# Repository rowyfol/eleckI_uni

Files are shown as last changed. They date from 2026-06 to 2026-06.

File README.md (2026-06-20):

# Discrete 2-to-1 Multiplexer (RTL Implementation)

A fully discrete 2-to-1 multiplexer built from NPN transistors, resistors, and diodes — no ICs. This project demonstrates the physical threshold where analog voltage becomes a digital decision.

---

## view schematic online:
[Open on Kicanvas](https://kicanvas.org/?repo=https%3A%2F%2Fgithub.com%2Frowyfol%2FElec101%2Ftree%2Fmain%2FKiCad)

---

## Overview

| | |
|---|---|
| **Course** | Electronics I |
| **Components** | 8× 2N3904 (NPN), Resistors (1K, 10K, 330Ω), Diodes (1N4148), LED, Potentiometer |
| **Logic Family** | RTL (Resistor-Transistor Logic) |
| **Input** | D₀, D₁ (data), S (select) |
| **Output** | Y (drives LED via Q8 buffer) |

The MUX implements the standard Boolean equation using a NAND-NAND structure:

$$Y = (D_0 \cdot \overline{S}) + (D_1 \cdot S)$$

Decomposed into three NAND gates for transistor-level implementation:

$$Y = \overline{\overline{(D_0 \cdot \overline{S})} \cdot \overline{(D_1 \cdot S)}}$$

---

## Circuit Architecture

### Block Diagram

```mermaid
graph LR
    S[S Input] --> Q1[NOT Gate<br/>Q1 Inverter]
    Q1 --> Sbar[S̄]

    D0[D0 Input] --> NAND1[NAND1<br/>Q2·Q3]
    Sbar --> NAND1

    D1[D1 Input] --> NAND2[NAND2<br/>Q4·Q5]
    S --> NAND2

    NAND1 --> N1[N1]
    NAND2 --> N2[N2]

    N1 --> NAND3[NAND3<br/>Q6·Q7]
    N2 --> NAND3

    NAND3 --> Y[Y Output]
    Y --> Q8[LED Driver<br/>Q8]
    Q8 --> LED[LED]
```

### Transistor-Level Schematic

```
+5V ────────────────────────────────────────────────
 │       │       │       │       │       │
[1K]   [1K]    [1K]    [1K]    [1K]   [330Ω]
 │       │       │       │       │       │
 ├─Q2─┐  ├─Q4─┐  ├─Q6─┐  │       │      LED
 │    │  │    │  │    │  │       │       │
D0   Q3  D1   Q5  N1   Q7  │       │      Q8
 │    │  │    │  │    │  │       │       │
 └─10K┘  └─10K┘  └─10K┘  │       │       │
    │       │       │      │       │       │
   GND     GND     GND    │       │      GND
                            │       │
                           Q1      [10K]
                            │       │
                            S───────┘
                           GND
```

### Stage Breakdown

| Stage | Transistors | Function | Equation |
|---|---|---|---|
| **Inverter** | Q1 | Produces S̄ from S | $\overline{S}$ |
| **NAND1** | Q2, Q3 | Computes $\overline{D_0 \cdot \overline{S}}$ | $N_1 = \overline{D_0 \cdot \overline{S}}$ |
| **NAND2** | Q4, Q5 | Computes $\overline{D_1 \cdot S}$ | $N_2 = \overline{D_1 \cdot S}$ |
| **NAND3** | Q6, Q7 | Final output | $Y = \overline{N_1 \cdot N_2}$ |
| **Driver** | Q8 | LED buffer | $\text{LED} = Y$ |

---

## Truth Table

| $S$ | $D_0$ | $D_1$ | $N_1$ | $N_2$ | $Y$ | LED |
|:---:|:---:|:---:|:---:|:---:|:---:|:---:|
| 0 | 0 | 0 | 1 | 1 | 0 | OFF |
| 0 | 1 | 0 | 0 | 1 | 1 | ON |
| 0 | 1 | 1 | 0 | 1 | 1 | ON |
| 1 | 0 | 0 | 1 | 1 | 0 | OFF |
| 1 | 0 | 1 | 1 | 0 | 1 | ON |
| 1 | 1 | 0 | 1 | 0 | 0 | OFF |
| 1 | 1 | 1 | 1 | 0 | 1 | ON |

**Key observation:** When $S=0$, output follows $D_0$. When $S=1$, output follows $D_1$.

---

## The Threshold Crossing Demo

Instead of a digital switch for the Select input, a **10K potentiometer** is wired as a voltage divider:

$$V_{wiper} = V_{CC} \times \frac{R_2}{R_1 + R_2}$$

As the knob rotates from 0 to 5V, the input transistor Q1 crosses its base-emitter threshold:

| $V_{wiper}$ | Q1 State | $\overline{S}$ | MUX Selects |
|:---:|:---:|:---:|:---:|
| 0V → 0.6V | OFF (Cutoff) | HIGH (~5V) | **D₀** |
| **~0.7V** | **Threshold** | **Transition** | **Snap** |
| 0.8V → 5V | ON (Saturation) | LOW (~0.2V) | **D₁** |

The LED does not fade — it **snaps** from one state to the other at approximately **0.7V**, demonstrating the physical origin of digital logic.

---

## Measured Voltages (Verification)

| Node | Expected | Measured | Status |
|---|---|---|---|
| Q1 Collector (S̄) | ~0V when S=HIGH | 26 mV | ✅ |
| Q2 Collector (NAND1) | ~5V when D₀=HIGH, S̄=LOW | 4.61 V | ✅ |
| Q4 Collector (NAND2) | ~5V when D₁=LOW | 4.61 V | ✅ |
| Q6 Collector (NAND3) | ~0V when both inputs HIGH | 57 mV | ✅ |

---

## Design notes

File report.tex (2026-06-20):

\documentclass[11pt,a4paper]{article}

% ============================================================
%  ELECTRONICS I PROJECT REPORT
% ============================================================

\usepackage[utf8]{inputenc}
\usepackage[T1]{fontenc}
\usepackage{geometry}
\usepackage{xcolor}
\usepackage{graphicx}
\usepackage{amsmath,amssymb}
\usepackage{booktabs}
\usepackage{caption}
\usepackage{enumitem}
\usepackage{fancyhdr}
\usepackage{titlesec}
\usepackage{tcolorbox}
\usepackage{tikz}
\usepackage{pgfplots}
\usepackage{float}
\usepackage{subcaption}
\usepackage{multicol}
\usepackage{wrapfig}
\pgfplotsset{compat=1.18}
\usetikzlibrary{arrows.meta,positioning,calc,shapes.gates.logic.IEC,decorations.pathmorphing,fit,backgrounds}

\geometry{left=2.8cm, right=2.8cm, top=2.8cm, bottom=3.2cm}

% ---------- PROFESSIONAL FONTS ----------
\usepackage{libertinus}
\usepackage{newtxmath}
\usepackage[scaled=0.95]{helvet}

% ---------- COLOR SCHEME ----------
\definecolor{primary}{RGB}{35, 55, 85}
\definecolor{accent}{RGB}{180, 95, 55}
\definecolor{secondary}{RGB}{75, 115, 145}
\definecolor{lightgray}{RGB}{240, 240, 238}
\definecolor{medgray}{RGB}{140, 140, 135}
\definecolor{darktext}{RGB}{25, 30, 35}

\pagecolor{white}
\color{darktext}

% ---------- HYPERREF ----------
\usepackage{hyperref}
\hypersetup{colorlinks=true, linkcolor=secondary, urlcolor=secondary, citecolor=medgray}

% ---------- SECTION STYLING ----------
\titleformat{\section}
  {\Large\bfseries\sffamily\color{primary}}
  {\thesection}{1em}{}
  [\vspace{-0.8em}\textcolor{accent}{\rule{\textwidth}{1.2pt}}]
\titleformat{\subsection}
  {\large\bfseries\sffamily\color{primary!85}}
  {\thesubsection}{1em}{}
\titleformat{\subsubsection}
  {\normalsize\bfseries\sffamily\color{medgray}}
  {\thesubsubsection}{1em}{}
\titlespacing*{\section}{0pt}{2.5em}{1.2em}
\titlespacing*{\subsection}{0pt}{2em}{0.8em}

% ---------- HEADER ----------
\pagestyle{fancy}
\fancyhf{}
\fancyhead[L]{\small\sffamily\textcolor{medgray}{Electronics I \;\textbullet\; Discrete 2-to-1 Multiplexer}}
\fancyhead[R]{\small\sffamily\textcolor{medgray}{\thepage}}
\renewcommand{\headrulewidth}{0.5pt}
\renewcommand{\headrule}{\hbox to\headwidth{\color{secondary}\leaders\hrule height \headrulewidth\hfill}}
\fancyfoot[C]{\footnotesize\textcolor{medgray}{\textit{}}}

% ---------- CAPTIONS ----------
\captionsetup{font=small, labelfont={bf,sf,color=primary}, labelsep=quad, format=plain}

% ---------- TCOLORBOX ----------
\tcbuselibrary{skins,breakable}

\newtcolorbox{note}[1][]{
  enhanced, colback=lightgray, colframe=medgray!40, arc=1mm, boxrule=0.6pt,
  left=10pt, right=10pt, top=8pt, bottom=8pt, fontupper=\small, #1
}

\newtcolorbox{fix}[1][]{
  enhanced, colback=white, colframe=accent!60, arc=1mm, boxrule=1pt,
  left=10pt, right=10pt, top=8pt, bottom=8pt, fontupper=\small,
  title={\small\bfseries\sffamily What Went Wrong}, fonttitle=\color{accent!80!black},
  attach boxed title to top left={yshift=-2mm,xshift=6mm},
  boxed title style={colback=accent!15, arc=1mm}, #1
}

\newtcolorbox{keypoint}[1][]{
  enhanced, colback=secondary!5, colframe=secondary!50, arc=1mm, boxrule=0.8pt,
  left=10pt, right=10pt, top=8pt, bottom=8pt, fontupper=\small,
  title={\small\bfseries\sffamily Key Point}, fonttitle=\color{secondary!80!black},
  attach boxed title to top left={yshift=-2mm,xshift=6mm},
  boxed title style={colback=secondary!15, arc=1mm}, #1
}

% ---------- CUSTOM ----------
\newcommand{\VCC}{+5\,\text{V}}
\newcommand{\GND}{0\,\text{V}}

% ============================================================
\begin{document}

% ============================================================
%  TITLE PAGE
% ============================================================
\begin{titlepage}
\begin{center}

\vspace*{1.5cm}

{\Large\sffamily\textcolor{secondary}{ELECTRONICS I PROJECT}}\\[1cm]

{\Huge\bfseries\textcolor{primary}{Building a 2-to-1 Multiplexer}}\\[0.25cm]
{\Huge\bfseries\textcolor{primary}{From Scratch }}\\[0.25cm]

\vspace{1.2cm}

\textcolor{accent}{\rule{0.7\textwidth}{1.5pt}}

\vspace{1cm}

\vspace{2cm}

\begin{tabular}{rl}
\\
\textbf{Course:} & Electronics I \\
\textbf{Supervisor:} & Dr. Shatrian \\
\textbf{Authors:} & Ashkan Namjoo \quad \& \quad Sadra Jahanshalo \\
\textbf{University:} & Shahid Bahonar University of Kerman \\
\textbf{Date:} & \today \\
\end{tabular}

\vfill

\end{center}
\end{titlepage}

% ============================================================
%  ABSTRACT
% ============================================================
\begin{tcolorbox}[
  enhanced, colback=lightgray, colframe=primary, arc=0mm, boxrule=1pt,
  left=12pt, right=12pt, top=10pt, bottom=10pt,
  title={\large\bfseries\sffamily Abstract},
  fonttitle=\color{white}, coltitle=white,
  attach boxed title to top left={yshift=-4mm, xshift=8mm},
  boxed title style={colback=primary, arc=0mm}
]
This report documents the design and construction of a fully discrete 2-to-1 multiplexer using only NPN transistors and resistors. The circuit implements the Boolean function $Y = (D_0 \cdot \overline{S}) + (D_1 \cdot S)$ using Resistor-Transistor Logic (RTL). After initial debugging to resolve a grounding issue in the output stage, the circuit was successfully verified against its truth table. Finally, a potentiometer was used to sweep the Select input voltage, revealing the sharp threshold ($\approx 0.7\,\text{V}$) where the transistor physically transitions from OFF to ON.
\end{tcolorbox}

\vspace{0.8em}
\tableofcontents
\newpage

% ============================================================
\section{Introduction}
% ============================================================

In our digital logic course, we mostly looked at multiplexers as abstract black boxes. You have inputs, a select line, and an output, and the select line chooses which input passes through. They look clean on paper, but we wanted to see how they actually work using physical wires and transistors.

So, we decided to build one from scratch. The rule was simple: no integrated circuits allowed. Just discrete transistors and resistors. If the logic holds up, it should work regardless of what level you build it at.

This project was split into two parts. First, we built the MUX and made sure it worked. Second, we replaced the Select switch with a potentiometer to watch what happens physically when you slowly sweep the voltage across the transistor's threshold.

% ============================================================
\section{Theory and Logic Design}
% ============================================================

\subsection{The Multiplexer Function}

A 2-to-1 multiplexer routes one of two data inputs to a single output based on a select bit. The Boolean equation is:

\begin{equation}
Y = (D_0 \cdot \overline{S}) + (D_1 \cdot S)
\label{eq:mux}
\end{equation}

When $S = 0$, the output equals $D_0$. When $S = 1$, the output equals $D_1$.

\subsection{From AND-OR to NAND-NAND}

Transistors are naturally good at making NAND gates, but not AND-OR structures directly. Using De Morgan's theorem, Equation~\eqref{eq:mux} becomes:

\begin{equation}
Y = \overline{\,\overline{(D_0 \cdot \overline{S})} \cdot \overline{(D_1 \cdot S)}\,}
\label{eq:nand}
\end{equation}

This requires:
\begin{itemize}[leftmargin=2em]
  \item One inverter to generate $\overline{S}$
  \item Three NAND gates (two for the inner terms, one for the final combination)
\end{itemize}

Figure~\ref{fig:logic} shows the complete logic diagram.

\begin{figure}[H]
\centering
\begin{tikzpicture}[
  logic gate IEC,
  line join=round,
  line cap=round,
  scale=1.15,
  transform shape
]

% --- Gates ---
\node[not gate, draw=primary, line width=1.5pt, minimum width=1cm, minimum height=0.8cm] (not) at (0,0) {};

\node[nand gate, draw=accent, line width=1.5pt, logic gate inputs=nn, minimum width=1.4cm, minimum height=1cm] (nand1) at (4.5,2.2) {};
\node[nand gate, draw=accent, line width=1.5pt, logic gate inputs=nn, minimum width=1.4cm, minimum height=1cm] (nand2) at (4.5,-2.2) {};
\node[nand gate, draw=secondary, line width=1.5pt, logic gate inputs=nn, minimum width=1.4cm, minimum height=1cm] (nand3) at (9,0) {};

% --- Inputs ---
\draw[primary, line width=1.2pt, -{Stealth}] (-2.5,0) -- (not.input) 
  node[pos=0.35, above, font=\small, fill=white, inner sep=2pt] {$S$};

\draw[primary, line width=1.2pt, -{Stealth}] (-2.5,2.2) -- (nand1.input 1) 
  node[pos=0.35, above, font=\small, fill=white, inner sep=2pt] {$D_0$};
\draw[primary, line width=1.2pt, -{Stealth}] (-2.5,-2.2) -- (nand2.input 2) 
  node[pos=0.35, below, font=\small, fill=white, inner sep=2pt] {$D_1$};

% --- S branch to NAND2 (top input) ---
\draw[primary, line width=1pt] (-2.5,0) -- (-1.2,0);
\fill[primary] (-1.2,0) circle (1.5pt);  % junction dot
\draw[primary, line width=1pt] (-1.2,0) -- (-1.2,-1.6) -- (nand2.input 1);

% --- Sbar from NOT to NAND1 (bottom input) ---
\draw[primary, line width=1pt] (not.output) -- (1.5,0) -- (1.5,1.6) -- (nand1.input 2);
\node[font=\small, fill=white, inner sep=2pt, anchor=west] at (1.55,0.8) {$\overline{S}$};

% --- NAND1 / NAND2 outputs to NAND3 ---
\draw[accent, line width=1.2pt] (nand1.output) -- ++(1.2,0) |- (nand3.input 1);
\draw[accent, line width=1.2pt] (nand2.output) -- ++(1.2,0) |- (nand3.input 2);

% --- Final output ---
\draw[secondary, line width=1.5pt, -{Stealth}] (nand3.output) -- ++(1.5,0) 
  node[right, font=\small, fill=white, inner sep=2pt] {$Y$};

% --- Gate labels ---
\node[font=\footnotesize\sffamily\bfseries, color=accent, above=0.25cm of nand1] {NAND1};
\node[font=\footnotesize\sffamily\bfseries, color=accent, below=0.25cm of nand2] {NAND2};
\node[font=\footnotesize\sffamily\bfseries, color=secondary, above=0.25cm of nand3] {NAND3};

\end{tikzpicture}
\caption{Logic diagram: NOT gate produces $\overline{S}$, NAND1 and NAND2 generate the intermediate terms, and NAND3 combines them for the final output.}
\label{fig:logic}
\end{figure}

\subsection{Why NAND Works for Transistors}

A NAND gate is built by placing two NPN transistors in series between the output node and ground. A pull-up resistor connects the output to +5V.

\begin{itemize}[leftmargin=2em]
  \item If either transistor is OFF, the path to ground is broken. The output stays HIGH.
  \item Only when both transistors are ON does current flow to ground, pulling the output LOW.
\end{itemize}

This is perfect for RTL because a single transistor can block the entire path.

% ============================================================
\section{Transistor-Level Implementation}
% ============================================================

\subsection{Stage 1: The Inverter (Q1)}

The inverter uses one NPN transistor with a 1K$\Omega$ collector pull-up and a 10K$\Omega$ base resistor.

\begin{itemize}[leftmargin=2em]
  \item Input LOW (0V): No base current. Transistor is OFF. The 1K$\Omega$ resistor pulls the output up to +5V.
  \item Input HIGH (5V): Base current flows. Transistor saturates. Output drops to roughly 0.2V.
\end{itemize}

\subsection{Stage 2: NAND Gates (Q2-Q7)}

Each NAND gate uses two transistors in series:

\begin{table}[H]
\centering
\caption{NAND gate transistor mapping.}
\begin{tabular}{@{}clll@{}}
\toprule
\textbf{Gate} & \textbf{Transistors} & \textbf{Input A} & \textbf{Input B} \\
\midrule
NAND1 & Q2 (top), Q3 (bottom) & $D_0$ & $\overline{S}$ \\
NAND2 & Q4 (top), Q5 (bottom) & $D_1$ & $S$ \\
NAND3 & Q6 (top), Q7 (bottom) & $N_1$ & $N_2$ \\
\bottomrule
\end{tabular}
\end{table}

The top transistor's collector connects to the pull-up resistor. Its emitter connects to the bottom transistor's collector. The bottom transistor's emitter goes straight to ground.

\subsection{Stage 3: Output Driver (Q8)}

Q8 acts as a simple buffer. When $Y$ is HIGH, base current flows through the 10K$\Omega$ resistor, Q8 turns ON, and the LED lights up. The 330$\Omega$ resistor limits the current to approximately 8mA to keep the LED safe.

\subsection{Complete Circuit Schematic}

Figure~\ref{fig:schematic} shows the full transistor-level implementation. This is the diagram we used to wire the breadboard.

\begin{figure}[H]
\centering

\caption{Complete RTL schematic of the 2-to-1 multiplexer. The circuit uses 8 transistors, 5 pull-up resistors (1K$\Omega$), 8 base resistors (10K$\Omega$), and one LED current-limiting resistor (330$\Omega$).}
\label{fig:schematic}
\end{figure}
% ============================================================
\section{Design Calculations}
% ============================================================

When building a circuit from discrete components, you cannot just guess resistor values. Every value affects how the transistor behaves. Here is how we chose ours.

\subsection{Base Resistor (10K$\Omega$)}

The base resistor controls how much current enters the transistor base. For the transistor to act as a solid switch, it must be in \textit{deep saturation}---not just barely on.

The collector current is set by the pull-up resistor:
\begin{equation}
I_C \approx \frac{V_{CC}}{R_C} = \frac{5\,\text{V}}{1\,\text{k}\Omega} = 5\,\text{mA}
\end{equation}

To guarantee saturation, we use a forced beta ($\beta_{forced}$) much lower than the transistor's actual current gain (typically 100--300 for 2N3904). We chose $\beta_{forced} \approx 12$:

\begin{equation}
I_B = \frac{I_C}{\beta_{forced}} = \frac{5\,\text{mA}}{12} \approx 0.4\,\text{mA}
\end{equation}

Then the base resistor is:
\begin{equation}
R_B = \frac{V_{CC} - V_{BE}}{I_B} = \frac{5\,\text{V} - 0.7\,\text{V}}{0.4\,\text{mA}} \approx 10.7\,\text{k}\Omega
\end{equation}

We used the standard value of 10K$\Omega$.
\subsection{Collector Pull-Up Resistor (1K$\Omega$)}

The pull-up resistor determines the logic HIGH level and the current drawn when the transistor is ON.

\begin{itemize}[leftmargin=2em]
  \item \textbf{Logic HIGH:} When the transistor is OFF, the pull-up holds the output near 5V.
  \item \textbf{Power:} When the transistor is ON, current flows through the resistor to ground. With $R_C = 1\,\text{k}\Omega$, this current is about 5mA---enough to drive the next stage but not so much that the transistor overheats.
  \item \textbf{Speed:} A smaller resistor charges the parasitic capacitance faster, but draws more power. 1K$\Omega$ is a standard compromise for RTL.
\end{itemize}

\subsection{LED Current-Limiting Resistor (330$\Omega$)}

The LED needs a specific current to glow brightly without burning out. Red LEDs typically drop about 1.8V.

\begin{equation}
I_{LED} = \frac{V_{CC} - V_{LED} - V_{CE(sat)}}{R_{LED}} = \frac{5\,\text{V} - 1.8\,\text{V} - 0.2\,\text{V}}{330\,\Omega} \approx 9\,\text{mA}
\end{equation}

This is a safe, bright current for a standard 5mm LED.

\subsection{Power Supply (LM7805)}

We used an LM7805 linear voltage regulator to provide a clean, stable +5V rail from a 9V battery. The LM7805 is a three-terminal regulator that maintains its output at exactly 5V regardless of load variations, as long as the input stays at least 2--3V above the output. This stability is important for RTL circuits because transistor thresholds and logic levels depend directly on the supply voltage.

\newpage

% ============================================================
\section{The Breadboard Build}
% ============================================================

Building this on a breadboard was honestly the hardest part. The schematic is clean, but the physical breadboard turns into a mess of crossing wires really fast. We figured out a few things that made it easier to handle.

\subsection{Wiring Strategy}

We divided the breadboard into clean sections:

\begin{enumerate}[leftmargin=2em]
  \item \textbf{Left side:} Input buttons and pull-down resistors
  \item \textbf{Center-left:} Inverter Q1 and NAND1 (Q2, Q3)
  \item \textbf{Center:} NAND2 (Q4, Q5)
  \item \textbf{Center-right:} NAND3 (Q6, Q7)
  \item \textbf{Right side:} LED driver Q8 and the output LED
\end{enumerate}
\subsection{The Breadboard Layout}

Figure~\ref{fig:breadboard} shows our actual physical build.

\begin{figure}[H]
\centering

\caption{The MUX constructed on a solderless breadboard. Power is supplied by an LM7805 5V voltage regulator.}
\label{fig:breadboard}
\end{figure}

\begin{center}
\begin{tikzpicture}
  \node[
    draw=primary, 
    line width=1.5pt, 
    rounded corners=5pt, 
    inner sep=15pt, 
    fill=lightgray,
    text width=0.5\textwidth,
    align=center,
    font=\small\sffamily
  ] 
  {\textcolor{primary}{\textbf{\url{https://www.tinkercad.com/things/4JDG91bPrdF-magnificent-leelo-luulia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}}}};
\end{tikzpicture}
\end{center}

\begin{keypoint}
\textbf{Setting D0 and D1 manually:} In this prototype, the data inputs are not controlled by switches. Instead, you must wire D0 and D1 directly to either +5V (HIGH) or GND (LOW). Look at the four small breadboards arranged together. Ignore the board with the LED and the one with the potentiometer. The top-left board is for D0, and the bottom-right board is for D1. On each board, find the wire that connects the 10K base resistor to the transistor base. Move that wire to the +5V rail for a HIGH input, or to the GND rail for a LOW input.

\end{keypoint}

\subsection{Verification Measurements}

After fixing the wiring, we verified every single node with a multimeter to be sure:

\begin{table}[H]
\centering
\caption{Post-fix voltage measurements.}
\begin{tabular}{@{}lccc@{}}
\toprule
\textbf{Node} & \textbf{Condition} & \textbf{Expected} & \textbf{Measured} \\
\midrule
Q1 Collector & $S = 5$V & $\approx$ 0V & 26 mV \\
Q2 Collector & $D_0 = 5$V, $S = 0$V & $\approx$ 5V & 4.61 V \\
Q4 Collector & $D_1 = 0$V, $S = 5$V & $\approx$ 5V & 4.61 V \\
Q6 Collector & $D_0 = 1$, $D_1 = 0$, $S = 0$ & $\approx$ 0V & 57 mV \\
\bottomrule
\end{tabular}
\end{table}

The small non-zero values (26mV, 57mV) are just the saturation voltage ($V_{CE(sat)}$) of the transistors. Because of the physical limits of the collector-emitter junction, it can't pull all the way down to a perfect, absolute 0V. This is totally normal.

% ============================================================
\section{The Threshold Experiment}
% ============================================================

\subsection{The Setup}

A potentiometer acts like an adjustable voltage divider. As you turn the knob, the wiper voltage changes smoothly from 0V up to 5V:

\begin{equation}
V_{wiper} = 5V \times \frac{R_2}{R_1 + R_2}
\end{equation}

We connected this wiper to the S input (the base of Q1). Then we slowly turned the knob while watching the LED output.

\subsection{What We Saw}

At first, the LED showed the state of $D_0$. As we turned the knob up, nothing happened for a while. Then, sooner than we expected, the LED started to show $D_1$.

With the 250K$\Omega$ potentiometer, the transition happened slightly earlier than the typical 0.7V threshold. Because the high source resistance limits the base current, the transistor begins to conduct at a lower $V_{BE}$ and enters saturation more gradually. The LED did not snap as sharply as it would with a lower-value potentiometer, but it still switched cleanly once the voltage crossed the active region.

Figure~\ref{fig:vtc} shows this voltage transfer characteristic visually.

\begin{figure}[H]
\centering
\begin{tikzpicture}
  \begin{axis}[
    width=12cm, height=7cm,
    xlabel={$V_{in}$ (S input) [V]},
    ylabel={$V_{out}$ ($\overline{S}$) [V]},
    xmin=0, xmax=5, ymin=0, ymax=5.5,
    grid=major, grid style={medgray!25},
    axis lines=left,
    tick label style={font=\small},
    label style={font=\small\sffamily},
    title={RTL Inverter Voltage Transfer Characteristic},
    title style={font=\normalsize\bfseries\sffamily}
  ]
  \addplot[color=primary, smooth, very thick] coordinates {
    (0,5) (0.4,5) (0.55,5) (0.6,4.8) (0.65,3.5) (0.7,2) (0.75,0.8) (0.8,0.3) (1,0.2) (5,0.2)
  };
  \addplot[color=accent, dashed, thick] coordinates {(0.7,0) (0.7,5)};
  \node[font=\small\sffamily, fill=white, inner sep=3pt] at (axis cs:0.7,5.3) {\textcolor{accent}{$V_{TH} \approx 0.7$V}};
  \node[font=\small\sffamily, fill=primary!10, rounded corners=2pt, inner sep=4pt] at (axis cs:0.3,4.5) {Q1 OFF};
  \node[font=\small\sffamily, fill=accent!10, rounded corners=2pt, inner sep=4pt] at (axis cs:2.5,4.5) {Q1 ON};
  \end{axis}
\end{tikzpicture}
\caption{The output snaps from HIGH to LOW right around the base-emitter threshold. There's no slow fade because the transistor current rises exponentially with voltage.}
\label{fig:vtc}
\end{figure}

\begin{table}[H]
\centering
\caption{Behavior as $V_S$ is swept from 0 to 5V.}
\begin{tabular}{@{}cccl@{}}
\toprule
\textbf{$V_S$} & \textbf{Q1 State} & \textbf{$\overline{S}$} & \textbf{MUX Behavior} \\
\midrule
0V -- 0.6V & OFF & HIGH ($\approx$5V) & Selects $D_0$ \\
$\approx$0.7V & Active region & Transition & LED may flicker slightly \\
0.8V -- 5V & ON (saturated) & LOW ($\approx$0.2V) & Selects $D_1$ \\
\bottomrule
\end{tabular}
\end{table}

\subsection{What This Means}

The LED doesn't fade; it snaps. One moment it's passing $D_0$, the next moment it's passing $D_1$. That snap happens right at the transistor's physical threshold, not at some magical abstract logic boundary. 

This is exactly what happens inside every modern digital chip. The "0" and "1" are just simple labels we put on voltages. The transistor doesn't actually know anything about digital logic—it only responds to voltage and current.

% ============================================================
\section{Results}
% ============================================================

We were able to verify the complete truth table with the working circuit:

\begin{table}[H]
\centering
\caption{Verified MUX truth table.}
\begin{tabular}{@{}ccccc@{}}
\toprule
\textbf{$S$} & \textbf{$D_0$} & \textbf{$D_1$} & \textbf{$Y$} & \textbf{LED} \\
\midrule
0 & 0 & 0 & 0 & OFF \\
0 & 1 & 0 & 1 & ON \\
0 & 1 & 1 & 1 & ON \\
1 & 0 & 0 & 0 & OFF \\
1 & 0 & 1 & 1 & ON \\
1 & 1 & 0 & 0 & OFF \\
1 & 1 & 1 & 1 & ON \\
\bottomrule
\end{tabular}
\end{table}

When $S = 0$, the output perfectly follows $D_0$. When $S = 1$, the output perfectly follows $D_1$. This completely confirms the logic holds up in the physical build.

% ============================================================
\section{Bill of Materials}
% ============================================================

\begin{table}[H]
\centering
\caption{Complete bill of materials for the discrete 2-to-1 MUX.}
\begin{tabular}{@{}llccc@{}}
\toprule
\textbf{Ref} & \textbf{Component} & \textbf{Value} & \textbf{Qty} & \textbf{Role} \\
\midrule
Q1 & NPN Transistor & 2N3904 & 1 & Inverter \\
Q2--Q3 & NPN Transistor & 2N3904 & 2 & NAND1 \\
Q4--Q5 & NPN Transistor & 2N3904 & 2 & NAND2 \\
Q6--Q7 & NPN Transistor & 2N3904 & 2 & NAND3 \\
Q8 & NPN Transistor & 2N3904 & 1 & LED Driver \\
R1, R6, R9, R11 & Resistor & 1K$\Omega$ & 4 & Collector pull-up \\
R2, R4, R5, R7, R8, R10, R13 & Resistor & 10K$\Omega$ & 7 & Base resistor \\
R3 & Resistor & 1K$\Omega$ & 1 & Q1 collector pull-up \\
R12 & Resistor & 330$\Omega$ & 1 & LED current limit \\
LED1 & LED & 5mm red & 1 & Output indicator \\
RV1 & Potentiometer & 250K$\Omega$ & 1 & Select input sweep \\
(optional, I didn't use them) SW1--SW3 & Push button & Tactile & 3 & D0, D1, S inputs \\
-- & Breadboard & MB-102 & 1 & Prototyping \\
-- & Power supply & 5V module & 1 & VCC rail \\
\bottomrule
\end{tabular}
\end{table}

% ============================================================
\section{Conclusion}
% ============================================================

Building a 2-to-1 multiplexer entirely out of discrete transistors took more debugging than we originally expected, but that's where we learned the most. Tracking down the ungrounded Q7 emitter taught us how important it is to trace voltages node by node instead of just guessing where the problem is.

The threshold experiment ended up being the highlight of the project. By sweeping the Select voltage with a potentiometer, we got to see the exact physical moment the transistor crosses from OFF to ON, which is the foundational physical behavior that makes all digital circuits possible.

% ============================================================
%  APPENDIX: QR CODE
% ============================================================
\section*{Project Repository}
\addcontentsline{toc}{section}{Project Repository}

All project files, including the interactive circuit simulator, presentation slides, and build photos, are available on GitHub:

\begin{center}
\begin{tikzpicture}
  \node[draw=primary, line width=1.5pt, rounded corners=5pt, inner sep=15pt, fill=lightgray] (box) at (0,0) {
    \begin{minipage}{0.5\textwidth}
    \centering
    \\[0.5em]
    {\small\sffamily\textcolor{primary}{\textbf{\url{https://github.com/rowyfol/Elec101}}}}
    \end{minipage}
  };
\end{tikzpicture}
\end{center}

\vspace{1em}
\begin{center}
\textcolor{medgray}{\small Scan the QR code or visit the URL to access the full project repository.}
\end{center}

\end{document}

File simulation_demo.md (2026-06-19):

<div align="center">

# ⚡ Discrete 2-to-1 MUX: A Hypertext Circuit Explorer

**A fully transistor-level 2-to-1 multiplexer with interactive state simulation**  
*Built with 8× 2N3904, resistors, diodes — zero ICs*

  

</div>

---

## 🎮 Interactive Control Panel

**Click any input combination below to jump to the live circuit state:**

| S | D₀ | D₁ | Expected Y | |
|:---:|:---:|:---:|:---:|:---:|
| [0](#state-000) | [0](#state-000) | [0](#state-000) | 0 (OFF) | [▶ Simulate](#state-000) |
| [0](#state-010) | [1](#state-010) | [0](#state-010) | 1 (ON) | [▶ Simulate](#state-010) |
| [0](#state-011) | [1](#state-011) | [1](#state-011) | 1 (ON) | [▶ Simulate](#state-011) |
| [1](#state-100) | [0](#state-100) | [0](#state-100) | 0 (OFF) | [▶ Simulate](#state-100) |
| [1](#state-101) | [0](#state-101) | [1](#state-101) | 1 (ON) | [▶ Simulate](#state-101) |
| [1](#state-110) | [1](#state-110) | [0](#state-110) | 0 (OFF) | [▶ Simulate](#state-110) |
| [1](#state-111) | [1](#state-111) | [1](#state-111) | 1 (ON) | [▶ Simulate](#state-111) |

**Or jump to the [Threshold Crossing Demo](#threshold-crossing) to see where analog becomes digital.**

---

## 📐 Circuit Architecture

```mermaid
graph LR
    S[S] -->|10K| Q1[NOT Q1]
    Q1 -->|S̄| NAND1[NAND1 Q2·Q3]
    D0[D0] -->|10K| NAND1
    NAND1 -->|N1| NAND3[NAND3 Q6·Q7]

    S -->|10K| NAND2[NAND2 Q4·Q5]
    D1[D1] -->|10K| NAND2
    NAND2 -->|N2| NAND3

    NAND3 -->|Y| Q8[Driver Q8]
    Q8 --> LED[LED]

    style NAND1 fill:#e8f5e9
    style NAND2 fill:#e3f2fd
    style NAND3 fill:#fff3e0
    style Q1 fill:#fce4ec
    style Q8 fill:#f3e5f5
```

**Boolean Equation:**

$$Y = (D_0 \cdot \overline{S}) + (D_1 \cdot S)$$

**NAND-NAND Implementation:**

$$Y = \overline{\overline{(D_0 \cdot \overline{S})} \cdot \overline{(D_1 \cdot S)}}$$

---

## 🔴 State: S=0, D₀=0, D₁=0

**Output: Y = 0 → LED OFF**

<details open>
<summary><b>Click to expand full circuit analysis</b></summary>

### Transistor States

| Transistor | Base Voltage | Condition | State | Collector |
|:---:|:---:|:---:|:---:|:---:|
| Q1 | 0V | S=0 | **OFF** | 5V (S̄=1) |
| Q2 | 0V | D₀=0 | **OFF** | — |
| Q3 | 5V | S̄=1 | **ON** | — |
| Q4 | 0V | D₁=0 | **OFF** | — |
| Q5 | 0V | S=0 | **OFF** | — |
| Q6 | 5V | N₁=1 | **ON** | — |
| Q7 | 5V | N₂=1 | **ON** | — |
| Q8 | 0.2V | Y=0 | **OFF** | — |

### Circuit Diagram (Live Voltages)

```
+5V ──[1K]──┬── N₁ = 5.0V (HIGH) ───────┬── Y = 0.2V (LOW) ───┬── LED = OFF
            │                           │                     │
           Q2(C)                       Q6(C)                 Q8(C)
            │                           │                     │
           Q2(B) ← 0.0V  OFF           Q6(B) ← 5.0V  ON      Q8(B) ← 0.2V  OFF
            │                           │                     │
           Q3(B) ← 5.0V  ON            Q7(B) ← 5.0V  ON      [10K]
            │                           │                     │
           Q3(E) ─── GND               Q7(E) ─── GND         GND

+5V ──[1K]──┬── N₂ = 5.0V (HIGH)
            │
           Q4(C)
            │
           Q4(B) ← 0.0V  OFF
            │
           Q5(B) ← 0.0V  OFF
            │
           Q5(E) ─── GND

+5V ──[1K]──┬── S̄ = 5.0V
            │
           Q1(C)
            │
           Q1(B) ← 0.0V  OFF
            │
           [10K]
            │
           GND
```

**Analysis:**
- NAND1: Q2 is OFF (D₀=0) → output N₁ stays HIGH (5V) regardless of Q3
- NAND2: Q4 is OFF (D₁=0) AND Q5 is OFF (S=0) → output N₂ stays HIGH (5V)
- NAND3: Both Q6 and Q7 are ON (N₁=5V, N₂=5V) → Y pulled to GND (~0.2V)
- Q8: Base at 0.2V → below V_BE threshold → LED OFF

</details>

---

## 🟢 State: S=0, D₀=1, D₁=0

**Output: Y = 1 → LED ON** ✅

<details>
<summary><b>Click to expand full circuit analysis</b></summary>

### Transistor States

| Transistor | Base Voltage | Condition | State | Collector |
|:---:|:---:|:---:|:---:|:---:|
| Q1 | 0V | S=0 | **OFF** | 5V (S̄=1) |
| Q2 | 5V | D₀=1 | **ON** | — |
| Q3 | 5V | S̄=1 | **ON** | — |
| Q4 | 0V | D₁=0 | **OFF** | — |
| Q5 | 0V | S=0 | **OFF** | — |
| Q6 | 0.3V | N₁=0 | **OFF** | — |
| Q7 | 5V | N₂=1 | **ON** | — |
| Q8 | 5V | Y=1 | **ON** | — |

### Circuit Diagram (Live Voltages)

```
+5V ──[1K]──┬── N₁ = 0.3V (LOW) ──────┬── Y = 5.0V (HIGH) ──┬── LED = ON ✅
            │                           │                     │
           Q2(C)                       Q6(C)                 Q8(C)
            │                           │                     │
           Q2(B) ← 5.0V  ON            Q6(B) ← 0.3V  OFF     Q8(B) ← 5.0V  ON
            │                           │                     │
           Q3(B) ← 5.0V  ON            Q7(B) ← 5.0V  ON      [10K]
            │                           │                     │
           Q3(E) ─── GND               Q7(E) ─── GND         GND

+5V ──[1K]──┬── N₂ = 5.0V (HIGH)
            │
           Q4(C)
            │
           Q4(B) ← 0.0V  OFF
            │
           Q5(B) ← 0.0V  OFF
            │
           Q5(E) ─── GND

+5V ──[1K]──┬── S̄ = 5.0V
            │
           Q1(C)
            │
           Q1(B) ← 0.0V  OFF
            │
           [10K]
            │
           GND
```

**Analysis:**
- NAND1: Both Q2 and Q3 are ON (D₀=1, S̄=1) → N₁ pulled LOW (~0.3V)
- NAND2: Q4 is OFF (D₁=0) → N₂ stays HIGH (5V)
- NAND3: Q6 is OFF (N₁=0.3V) → even though Q7 is ON, series path is broken → Y stays HIGH (5V)
- Q8: Base at 5V → fully ON → LED ON

**This is the correct MUX behavior:** S=0 selects D₀=1 → Y=1

</details>

---

## 🟢 State: S=0, D₀=1, D₁=1

**Output: Y = 1 → LED ON** ✅

<details>
<summary><b>Click to expand full circuit analysis</b></summary>

### Transistor States

| Transistor | Base Voltage | Condition | State | Collector |
|:---:|:---:|:---:|:---:|:---:|
| Q1 | 0V | S=0 | **OFF** | 5V (S̄=1) |
| Q2 | 5V | D₀=1 | **ON** | — |
| Q3 | 5V | S̄=1 | **ON** | — |
| Q4 | 5V | D₁=1 | **ON** | — |
| Q5 | 0V | S=0 | **OFF** | — |
| Q6 | 0.3V | N₁=0 | **OFF** | — |
| Q7 | 5V | N₂=1 | **ON** | — |
| Q8 | 5V | Y=1 | **ON** | — |

### Circuit Diagram (Live Voltages)

```
+5V ──[1K]──┬── N₁ = 0.3V (LOW) ──────┬── Y = 5.0V (HIGH) ──┬── LED = ON ✅
            │                           │                     │
           Q2(C)                       Q6(C)                 Q8(C)
            │                           │                     │
           Q2(B) ← 5.0V  ON            Q6(B) ← 0.3V  OFF     Q8(B) ← 5.0V  ON
            │                           │                     │
           Q3(B) ← 5.0V  ON            Q7(B) ← 5.0V  ON      [10K]
            │                           │                     │
           Q3(E) ─── GND               Q7(E) ─── GND         GND

+5V ──[1K]──┬── N₂ = 5.0V (HIGH)
            │
           Q4(C)
            │
           Q4(B) ← 5.0V  ON
            │
           Q5(B) ← 0.0V  OFF
            │
           Q5(E) ─── GND

+5V ──[1K]──┬── S̄ = 5.0V
            │
           Q1(C)
            │
           Q1(B) ← 0.0V  OFF
            │
           [10K]
            │
           GND
```

**Analysis:**
- Same as State 010. NAND1 pulls N₁ LOW because both Q2 and Q3 are ON.
- NAND2: Q5 is OFF (S=0) so N₂ stays HIGH regardless of Q4.
- NAND3: Q6 OFF → Y stays HIGH.
- MUX selects D₀=1 → Y=1

</details>

---

## 🔴 State: S=1, D₀=0, D₁=0

**Output: Y = 0 → LED OFF**

<details>
<summary><b>Click to expand full circuit analysis</b></summary>

### Transistor States

| Transistor | Base Voltage | Condition | State | Collector |
|:---:|:---:|:---:|:---:|:---:|
| Q1 | 5V | S=1 | **ON** | 0.2V (S̄=0) |
| Q2 | 0V | D₀=0 | **OFF** | — |
| Q3 | 0.2V | S̄=0 | **OFF** | — |
| Q4 | 0V | D₁=0 | **OFF** | — |
| Q5 | 5V | S=1 | **ON** | — |
| Q6 | 5V | N₁=1 | **ON** | — |
| Q7 | 5V | N₂=1 | **ON** | — |
| Q8 | 0.2V | Y=0 | **OFF** | — |

### Circuit Diagram (Live Voltages)

```
+5V ──[1K]──┬── N₁ = 5.0V (HIGH) ───────┬── Y = 0.2V (LOW) ───┬── LED = OFF
            │                           │                     │
           Q2(C)                       Q6(C)                 Q8(C)
            │                           │                     │
           Q2(B) ← 0.0V  OFF           Q6(B) ← 5.0V  ON      Q8(B) ← 0.2V  OFF
            │                           │                     │
           Q3(B) ← 0.2V  OFF           Q7(B) ← 5.0V  ON      [10K]
            │                           │                     │
           Q3(E) ─── GND               Q7(E) ─── GND         GND

+5V ──[1K]──┬── N₂ = 5.0V (HIGH)
            │
           Q4(C)
            │
           Q4(B) ← 0.0V  OFF
            │
           Q5(B) ← 5.0V  ON
            │
           Q5(E) ─── GND

+5V ──[1K]──┬── S̄ = 0.2V
            │
           Q1(C)
            │
           Q1(B) ← 5.0V  ON
            │
           [10K]
            │
           GND
```

**Analysis:**
- Q1 is ON (S=5V) → S̄ pulled LOW (~0.2V)
- NAND1: Q2 OFF (D₀=0) → N₁ stays HIGH
- NAND2: Q4 OFF (D₁=0) → N₂ stays HIGH
- NAND3: Both Q6 and Q7 ON → Y pulled LOW
- LED OFF

</details>

---

## 🟢 State: S=1, D₀=0, D₁=1

**Output: Y = 1 → LED ON** ✅

<details>
<summary><b>Click to expand full circuit analysis</b></summary>

### Transistor States

| Transistor | Base Voltage | Condition | State | Collector |
|:---:|:---:|:---:|:---:|:---:|
| Q1 | 5V | S=1 | **ON** | 0.2V (S̄=0) |
| Q2 | 0V | D₀=0 | **OFF** | — |
| Q3 | 0.2V | S̄=0 | **OFF** | — |
| Q4 | 5V | D₁=1 | **ON** | — |
| Q5 | 5V | S=1 | **ON** | — |
| Q6 | 5V | N₁=1 | **ON** | — |
| Q7 | 0.3V | N₂=0 | **OFF** | — |
| Q8 | 5V | Y=1 | **ON** | — |

### Circuit Diagram (Live Voltages)

```
+5V ──[1K]──┬── N₁ = 5.0V (HIGH) ───────┬── Y = 5.0V (HIGH) ──┬── LED = ON ✅
            │                           │                     │
           Q2(C)                       Q6(C)                 Q8(C)
            │                           │                     │
           Q2(B) ← 0.0V  OFF           Q6(B) ← 5.0V  ON      Q8(B) ← 5.0V  ON
            │                           │                     │
           Q3(B) ← 0.2V  OFF           Q7(B) ← 0.3V  OFF     [10K]
            │                           │                     │
           Q3(E) ─── GND               Q7(E) ─── GND         GND

+5V ──[1K]──┬── N₂ = 0.3V (LOW)
            │
           Q4(C)
            │
           Q4(B) ← 5.0V  ON
            │
           Q5(B) ← 5.0V  ON
            │
           Q5(E) ─── GND

+5V ──[1K]──┬── S̄ = 0.2V
            │
           Q1(C)
            │
           Q1(B) ← 5.0V  ON
            │
           [10K]
            │
           GND
```

**Analysis:**
- NAND2: Both Q4 and Q5 are ON (D₁=1, S=1) → N₂ pulled LOW (~0.3V)
- NAND1: Q3 is OFF (S̄=0.2V) → N₁ stays HIGH
- NAND3: Q7 is OFF (N₂=0.3V) → series path broken → Y stays HIGH
- Q8 ON → LED ON

**Correct MUX behavior:** S=1 selects D₁=1 → Y=1

</details>

---

## 🔴 State: S=1, D₀=1, D₁=0

**Output: Y = 0 → LED OFF**

<details>
<summary><b>Click to expand full circuit analysis</b></summary>

### Transistor States

| Transistor | Base Voltage | Condition | State | Collector |
|:---:|:---:|:---:|:---:|:---:|
| Q1 | 5V | S=1 | **ON** | 0.2V (S̄=0) |
| Q2 | 5V | D₀=1 | **ON** | — |
| Q3 | 0.2V | S̄=0 | **OFF** | — |
| Q4 | 0V | D₁=0 | **OFF** | — |
| Q5 | 5V | S=1 | **ON** | — |
| Q6 | 5V | N₁=1 | **ON** | — |
| Q7 | 5V | N₂=1 | **ON** | — |
| Q8 | 0.2V | Y=0 | **OFF** | — |

### Circuit Diagram (Live Voltages)

```
+5V ──[1K]──┬── N₁ = 5.0V (HIGH) ───────┬── Y = 0.2V (LOW) ───┬── LED = OFF
            │                           │                     │
           Q2(C)                       Q6(C)                 Q8(C)
            │                           │                     │
           Q2(B) ← 5.0V  ON            Q6(B) ← 5.0V  ON      Q8(B) ← 0.2V  OFF
            │                           │                     │
           Q3(B) ← 0.2V  OFF           Q7(B) ← 5.0V  ON      [10K]
            │                           │                     │
           Q3(E) ─── GND               Q7(E) ─── GND         GND

+5V ──[1K]──┬── N₂ = 5.0V (HIGH)
            │
           Q4(C)
            │
           Q4(B) ← 0.0V  OFF
            │
           Q5(B) ← 5.0V  ON
            │
           Q5(E) ─── GND

+5V ──[1K]──┬── S̄ = 0.2V
            │
           Q1(C)
            │
           Q1(B) ← 5.0V  ON
            │
           [10K]
            │
           GND
```

**Analysis:**
- NAND1: Q3 is OFF (S̄=0.2V) → N₁ stays HIGH
- NAND2: Q4 is OFF (D₁=0) → N₂ stays HIGH
- NAND3: Both Q6 and Q7 ON → Y pulled LOW
- LED OFF

**Correct MUX behavior:** S=1 selects D₁=0 → Y=0

</details>

---

## 🟢 State: S=1, D₀=1, D₁=1

**Output: Y = 1 → LED ON** ✅

<details>
<summary><b>Click to expand full circuit analysis</b></summary>

### Transistor States

| Transistor | Base Voltage | Condition | State | Collector |
|:---:|:---:|:---:|:---:|:---:|
| Q1 | 5V | S=1 | **ON** | 0.2V (S̄=0) |
| Q2 | 5V | D₀=1 | **ON** | — |
| Q3 | 0.2V | S̄=0 | **OFF** | — |
| Q4 | 5V | D₁=1 | **ON** | — |
| Q5 | 5V | S=1 | **ON** | — |
| Q6 | 5V | N₁=1 | **ON** | — |
| Q7 | 0.3V | N₂=0 | **OFF** | — |
| Q8 | 5V | Y=1 | **ON** | — |

### Circuit Diagram (Live Voltages)

```
+5V ──[1K]──┬── N₁ = 5.0V (HIGH) ───────┬── Y = 5.0V (HIGH) ──┬── LED = ON ✅
            │                           │                     │
           Q2(C)                       Q6(C)                 Q8(C)
            │                           │                     │
           Q2(B) ← 5.0V  ON            Q6(B) ← 5.0V  ON      Q8(B) ← 5.0V  ON
            │                           │                     │
           Q3(B) ← 0.2V  OFF           Q7(B) ← 0.3V  OFF     [10K]
            │                           │                     │
           Q3(E) ─── GND               Q7(E) ─── GND         GND

+5V ──[1K]──┬── N₂ = 0.3V (LOW)
            │
           Q4(C)
            │
           Q4(B) ← 5.0V  ON
            │
           Q5(B) ← 5.0V  ON
            │
           Q5(E) ─── GND

+5V ──[1K]──┬── S̄ = 0.2V
            │
           Q1(C)
            │
           Q1(B) ← 5.0V  ON
            │
           [10K]
            │
           GND
```

**Analysis:**
- NAND2: Both Q4 and Q5 ON → N₂ pulled LOW
- NAND3: Q7 OFF → Y stays HIGH
- Q8 ON → LED ON

**Correct MUX behavior:** S=1 selects D₁=1 → Y=1

</details>

---

## ⚡ The Threshold Crossing Demo

**The most interesting part of this project:** Instead of a digital switch for the Select input, a **10K potentiometer** is wired as a voltage divider.

### The Potentiometer Circuit

```
+5V ───[10K Potentiometer]─── GND
            │
         Wiper
            │
            └──→ S (to Q1 base via 10K resistor)
```

**Equation:**

$$V_{wiper} = V_{CC} \times \frac{R_2}{R_1 + R_2}$$

### What Happens When You Turn the Knob

| $V_{wiper}$ | Q1 State | $\overline{S}$ | MUX Behavior |
|:---:|:---:|:---:|:---|
| **0.0V → 0.6V** | OFF (Cutoff) | HIGH (~5V) | LED shows **D₀** state |
| **~0.7V** | **Threshold** | **Transition** | LED **snaps** suddenly |
| **0.8V → 5.0V** | ON (Saturation) | LOW (~0.2V) | LED shows **D₁** state |

### The Physics

A BJT is governed by the diode equation:

$$I_C \approx I_S \cdot e^{V_{BE}/V_T}$$

Where $V_T = kT/q \approx 26\text{mV}$ at room temperature.

Because of this exponential relationship, a change of just **60mV** in $V_{BE}$ changes the collector current by a factor of **10×**. This is why the transition looks like a "digital switch" even though it is fundamentally a continuous analog process.

### The "Snap" Explained

```
Vout (S̄)
  5V │████████
     │        ╲
     │         ╲
     │          ╲
 2.5V│           ╲
     │            ╲
     │             ╲
  0V │              ████████
     └────┬──────────────────→ Vin (S)
          │
        0.7V
      THRESHOLD
```

**The LED does not fade.** It snaps from one state to the other at approximately **0.7V** — the exact boundary where analog voltage becomes a digital decision.

---

## 🔧 Build Log & Debugging

| Problem | Symptom | Root Cause | Fix |
|---|---|---|-----|
| LED always ON | Y stuck at 5V regardless of inputs | NAND3 (Q6·Q7) output not pulling LOW — Q7 emitter not grounded | Rewired Q7 emitter to GND rail |
| Diode AND gate not working | Output stuck at 5V | Pull-down resistors on wrong side of push buttons | Moved 10K resistors to same side as diode anodes |
| Diode direction wrong | Output drooped to 4.5V then recovered | Diodes reversed (band pointing toward button instead of output) | Flipped all 4 diodes |

**Measured Verification:**

| Node | Expected | Measured | Status |
|---|---|---|---|
| Q1 Collector (S̄) | ~0V when S=HIGH | **26 mV** | ✅ |
| Q2 Collector (NAND1) | ~5V | **4.61 V** | ✅ |
| Q4 Collector (NAND2) | ~5V | **4.61 V** | ✅ |
| Q6 Collector (NAND3) | ~0V | **57 mV** | ✅ |

---

## 📋 Component List

| Component | Value | Quantity | Role |
|---|---|---|---|
| 2N3904 | NPN | 8 | Q1–Q8 |
| Resistor | 1KΩ | 5 | Pull-up (collectors) |
| Resistor | 10KΩ | 8 | Base resistors, pull-downs |
| Resistor | 330Ω | 1 | LED current limit |
| Diode | 1N4148 | 4 | Input AND gates |
| LED | 5mm | 1 | Output indicator |
| Potentiometer | 10KΩ | 1 | Select input sweep |
| Push Button | Tactile | 3 | D₀, D₁, S (optional) |
| Breadboard | MB-102 | 1 | Prototyping |
| Power Supply | 5V | 1 | VCC rail |

---

## 🎯 Key Takeaways

1. **Digital logic is physically analog.** "0" and "1" are just regions on a continuous voltage curve separated by a transistor threshold (~0.7V).

2. **RTL has poor noise margins.** The LOW level is ~0.2–0.4V and the threshold is ~0.7V. This is why modern logic families (TTL, CMOS) were developed.

3. **Series NAND gates accumulate VCE(sat).** Two saturated transistors in series drop ~0.4V total, leaving very little margin before the next stage turns on.

4. **Debugging is where you learn.** The circuit "worked on paper" but failed on the breadboard. Tracing voltages node by node revealed the real problem — a floating emitter.

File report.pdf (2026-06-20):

## ELECTRONICS I PROJECT

# Building a 2-to-1 Multiplexer From Scratch

Course: Electronics I
Supervisor: Dr. Shatrian
Authors: Ashkan Namjoo | & | Sadra Jahanshalo
University: Shahid Bahonar University of Kerman Date: June 20, 2026

Electronics I • Discrete 2-to-1 Multiplexer | 1

Abstract
This report documents the design and construction of a fully discrete 2-to-1 multiplexer using only NPN transistors and resistors. The circuit implements the Boolean function Y = (D0 · S) + (D1 · S) using Resistor-Transistor Logic (RTL). After initial debugging to resolve a grounding issue in the output stage, the circuit was successfully verified against its truth table. Finally, a potentiometer was used to sweep the Select input voltage, revealing the sharp threshold (≈ 0.7 V) where the transistor physically transitions from OFF to ON.

## Contents

1 Introduction | 2
2 Theory and Logic Design | 2
3 Transistor-Level Implementation | 3
4 Design Calculations | 5
5 The Breadboard Build | 7
6 The Threshold Experiment | 8
7 Results | 9
8 Bill of Materials | 10
9 Conclusion | 10
Project Repository | 11

## 1 Introduction

In our digital logic course, we mostly looked at multiplexers as abstract black boxes. You have inputs, a select line, and an output, and the select line chooses which input passes through. They look clean on paper, but we wanted to see how they actually work using physical wires and transistors. So, we decided to build one from scratch. The rule was simple: no integrated circuits allowed. Just discrete transistors and resistors. If the logic holds up, it should work regardless of what level you build it at.
This project was split into two parts. First, we built the MUX and made sure it worked. Second, we replaced the Select switch with a potentiometer to watch what happens physically when you slowly sweep the voltage across the transistor’s threshold.

## 2 Theory and Logic Design

### 2.1 The Multiplexer Function

A 2-to-1 multiplexer routes one of two data inputs to a single output based on a select bit. The Boolean equation is:

Y = (D0 · S) + (D1 · S) | (1)

When S = 0, the output equals D0. When S = 1, the output equals D1.

### 2.2 From AND-OR to NAND-NAND

Transistors are naturally good at making NAND gates, but not AND-OR structures directly. Using De Morgan’s theorem, Equation (1) becomes:

Y = (D0 · S) · (D1 · S) | (2)

This requires:

- One inverter to generate S
- Three NAND gates (two for the inner terms, one for the final combination)

Figure 1 shows the complete logic diagram.

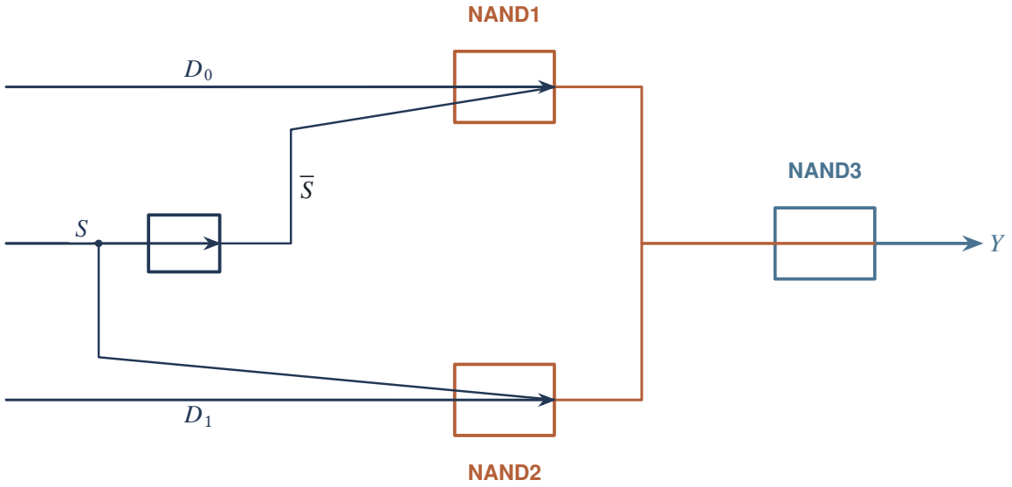
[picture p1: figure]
NAND1; NAND2; NAND3

Figure 1 Logic diagram: NOT gate produces S, NAND1 and NAND2 generate the intermediate terms, and NAND3 combines them for the final output.

### 2.3 Why NAND Works for Transistors

A NAND gate is built by placing two NPN transistors in series between the output node and ground. A pull-up resistor connects the output to +5V.

- If either transistor is OFF, the path to ground is broken. The output stays HIGH.
- Only when both transistors are ON does current flow to ground, pulling the output LOW.

This is perfect for RTL because a single transistor can block the entire path.

## 3 Transistor-Level Implementation

### 3.1 Stage 1: The Inverter (Q1)

The inverter uses one NPN transistor with a 1KΩ collector pull-up and a 10KΩ base resistor.

- Input LOW (0V): No base current. Transistor is OFF. The 1KΩ resistor pulls the output up to +5V.
- Input HIGH (5V): Base current flows. Transistor saturates. Output drops to roughly 0.2V.

### 3.2 Stage 2: NAND Gates (Q2-Q7)

Each NAND gate uses two transistors in series:

Table 1 NAND gate transistor mapping.

Gate | Transistors | Input A Input B
NAND1 | Q2 (top), Q3 (bottom) D0 | S
NAND2 | Q4 (top), Q5 (bottom) D1 | S
NAND3 | Q6 (top), Q7 (bottom) N1 | N2

The top transistor’s collector connects to the pull-up resistor. Its emitter connects to the bottom transistor’s collector. The bottom transistor’s emitter goes straight to ground.

### 3.3 Stage 3: Output Driver (Q8)

Q8 acts as a simple buffer. When Y is HIGH, base current flows through the 10KΩ resistor, Q8 turns ON, and the LED lights up. The 330Ω resistor limits the current to approximately 8mA to keep the LED safe.

### 3.4 Complete Circuit Schematic

Figure 2 shows the full transistor-level implementation. This is the diagram we used to wire the breadboard.

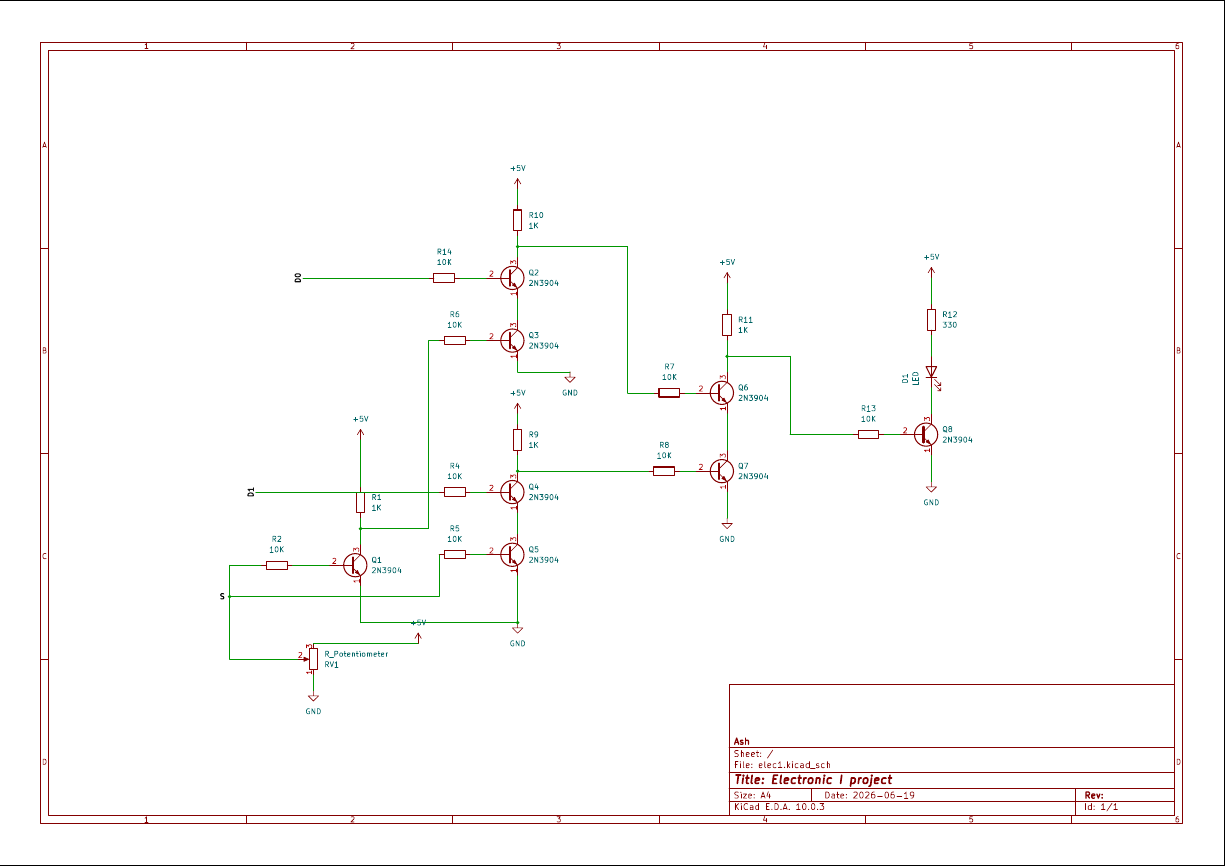
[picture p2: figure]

Figure 2 Complete RTL schematic of the 2-to-1 multiplexer. The circuit uses 8 transistors, 5 pull-up resistors (1KΩ), 8 base resistors (10KΩ), and one LED current-limiting resistor (330Ω).

## 4 Design Calculations

When building a circuit from discrete components, you cannot just guess resistor values. Every value affects how the transistor behaves. Here is how we chose ours.

### 4.1 Base Resistor (10KΩ)

The base resistor controls how much current enters the transistor base. For the transistor to act as a solid switch, it must be in deep saturation—not just barely on.
The collector current is set by the pull-up resistor:

IC ≈

VCC

RC

=

5 V

1 kΩ

= 5 mA | (3)

To guarantee saturation, we use a forced beta (β f or ced) much lower than the transistor’s actual current gain (typically 100–300 for 2N3904). We chose β f or ced ≈ 12:

IB =

IC

β f or ced

=

5 mA

12

≈ 0.4 mA | (4)

Then the base resistor is:

RB =

VCC − VBE

IB

=

5 V − 0.7 V

0.4 mA

≈ 10.7 kΩ | (5)

We used the standard value of 10KΩ.

### 4.2 Collector Pull-Up Resistor (1KΩ)

The pull-up resistor determines the logic HIGH level and the current drawn when the transistor is ON.

- Logic HIGH: When the transistor is OFF, the pull-up holds the output near 5V.
- Power: When the transistor is ON, current flows through the resistor to ground. With RC = 1 kΩ, this current is about 5mA—enough to drive the next stage but not so much that the transistor overheats.
- Speed: A smaller resistor charges the parasitic capacitance faster, but draws more power. 1KΩ is a standard compromise for RTL.

### 4.3 LED Current-Limiting Resistor (330Ω)

The LED needs a specific current to glow brightly without burning out. Red LEDs typically drop about 1.8V.

ILED =

VCC − VLED − VCE (sat)

RLED

=

5 V − 1.8 V − 0.2 V

330 Ω

≈ 9 mA | (6)

This is a safe, bright current for a standard 5mm LED.

### 4.4 Power Supply (LM7805)

We used an LM7805 linear voltage regulator to provide a clean, stable +5V rail from a 9V battery. The LM7805 is a three-terminal regulator that maintains its output at exactly 5V regardless of load variations, as long as the input stays at least 2–3V above the output. This stability is important for RTL circuits because transistor thresholds and logic levels depend directly on the supply voltage.

## 5 The Breadboard Build

Building this on a breadboard was honestly the hardest part. The schematic is clean, but the physical breadboard turns into a mess of crossing wires really fast. We figured out a few things that made it easier to handle.

### 5.1 Wiring Strategy

We divided the breadboard into clean sections:

1. Left side: Input buttons and pull-down resistors
2. Center-left: Inverter Q1 and NAND1 (Q2, Q3)
3. Center: NAND2 (Q4, Q5)
4. Center-right: NAND3 (Q6, Q7)
5. Right side: LED driver Q8 and the output LED

### 5.2 The Breadboard Layout

Figure 3 shows our actual physical build.

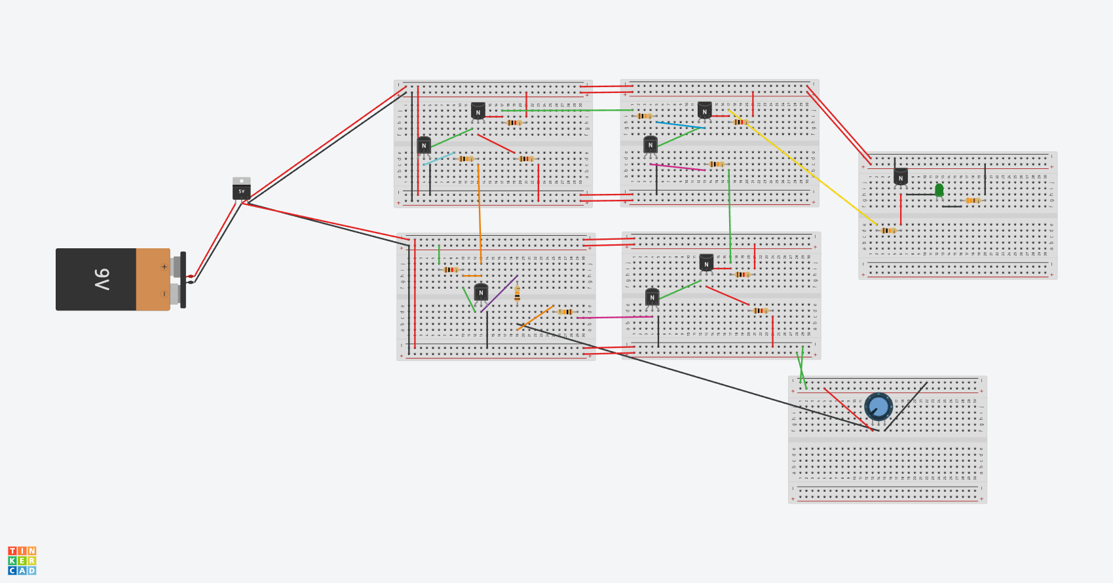
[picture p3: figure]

Figure 3 The MUX constructed on a solderless breadboard. Power is supplied by an LM7805 5V voltage regulator.

https://www.tinkercad.com/things/4JDG91bPrdF-magnificent-leelo-luulia?sharecode=P3w_
72XjgpzeE71dH-Q66N6LDBuPjUM-qISmru5L_ fw (https://www.tinkercad.com/things/4JDG91bPrdF-magnificent-leelo-luulia)

Key Point

Setting D0 and D1 manually: In this prototype, the data inputs are not controlled by switches. Instead, you must wire D0 and D1 directly to either +5V (HIGH) or GND (LOW). Look at the four small breadboards arranged together. Ignore the board with the LED and the one with the potentiometer. The top-left board is for D0, and the bottom-right board is for D1. On each board, find the wire that connects the 10K base resistor to the transistor base. Move that wire to the +5V rail for a HIGH input, or to the GND rail for a LOW input.

### 5.3 Verification Measurements

After fixing the wiring, we verified every single node with a multimeter to be sure:

Table 2 Post-fix voltage measurements.

Node | Condition | Expected Measured
Q1 Collector | S = 5V | ≈ 0V | 26 mV
Q2 Collector | D0 = 5V, S = 0V | ≈ 5V | 4.61 V
Q4 Collector | D1 = 0V, S = 5V | ≈ 5V | 4.61 V
Q6 Collector | D0 = 1, D1 = 0, S = 0 | ≈ 0V | 57 mV

The small non-zero values (26mV, 57mV) are just the saturation voltage (VCE (sat)

) of the transistors. Because of the physical limits of the collector-emitter junction, it can’t pull all the way down to a perfect, absolute 0V. This is totally normal.

## 6 The Threshold Experiment

### 6.1 The Setup

A potentiometer acts like an adjustable voltage divider. As you turn the knob, the wiper voltage changes smoothly from 0V up to 5V:

Vwi per = 5V ×

R2

R1 + R2

(7)

We connected this wiper to the S input (the base of Q1). Then we slowly turned the knob while watching the LED output.

### 6.2 What We Saw

At first, the LED showed the state of D0. As we turned the knob up, nothing happened for a while. Then, sooner than we expected, the LED started to show D1.
With the 250KΩ potentiometer, the transition happened slightly earlier than the typical 0.7V threshold. Because the high source resistance limits the base current, the transistor begins to con-duct at a lower VBE and enters saturation more gradually. The LED did not snap as sharply as it would with a lower-value potentiometer, but it still switched cleanly once the voltage crossed the active region.
Figure 4 shows this voltage transfer characteristic visually.

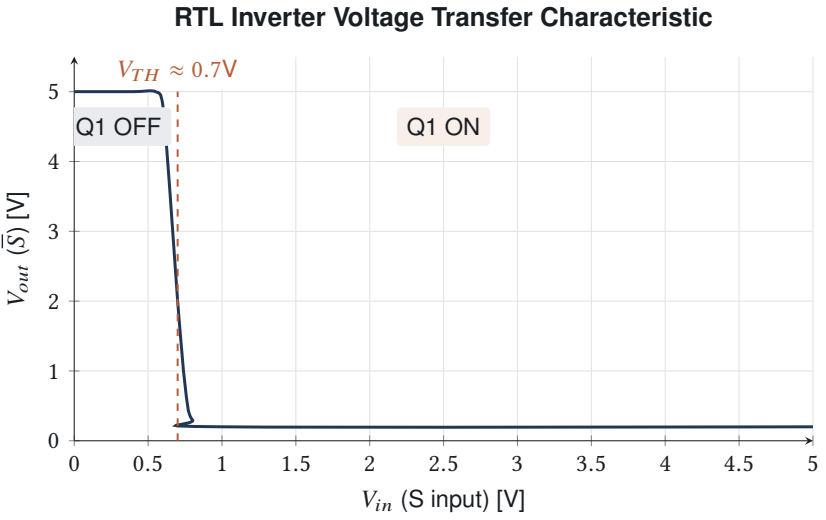
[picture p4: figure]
VTH ≈ 0.7V; Q1 OFF; Vin (S input) [V]; Vout (S) [V]; RTL Inverter Voltage Transfer Characteristic

Figure 4 The output snaps from HIGH to LOW right around the base-emitter threshold. There’s no slow fade because the transistor current rises exponentially with voltage.

Table 3 Behavior as VS is swept from 0 to 5V.

VS | Q1 State | S | MUX Behavior
0V – 0.6V | OFF | HIGH (≈5V) | Selects D0
≈0.7V | Active region | Transition | LED may flicker slightly
0.8V – 5V | ON (saturated) LOW (≈0.2V) Selects D1

### 6.3 What This Means

The LED doesn’t fade; it snaps. One moment it’s passing D0, the next moment it’s passing D1. That snap happens right at the transistor’s physical threshold, not at some magical abstract logic boundary.
This is exactly what happens inside every modern digital chip. The "0" and "1" are just simple labels we put on voltages. The transistor doesn’t actually know anything about digital logic—it only responds to voltage and current.

## 7 Results

We were able to verify the complete truth table with the working circuit:

Table 4 Verified MUX truth table.

S | D0 | D1 | Y | LED
0 | 0 | 0 | 0 | OFF
0 | 1 | 0 | 1 | ON
0 | 1 | 1 | 1 | ON
1 | 0 | 0 | 0 | OFF
1 | 0 | 1 | 1 | ON
1 | 1 | 0 | 0 | OFF
1 | 1 | 1 | 1 | ON

When S = 0, the output perfectly follows D0. When S = 1, the output perfectly follows D1. This completely confirms the logic holds up in the physical build.

## 8 Bill of Materials

Table 5 Complete bill of materials for the discrete 2-to-1 MUX.

Ref | Component | Value | Qty | Role
Q1 | NPN Transistor | 2N3904 | 1 | Inverter
Q2–Q3 | NPN Transistor | 2N3904 | 2 | NAND1
Q4–Q5 | NPN Transistor | 2N3904 | 2 | NAND2
Q6–Q7 | NPN Transistor | 2N3904 | 2 | NAND3
Q8 | NPN Transistor | 2N3904 | 1 | LED Driver
R1, R6, R9, R11 | Resistor | 1KΩ | 4 | Collector pull-up
R2, R4, R5, R7, R8, R10, R13 | Resistor | 10KΩ | 7 | Base resistor
R3 | Resistor | 1KΩ | 1 | Q1 collector pull-up
R12 | Resistor | 330Ω | 1 | LED current limit
LED1 | LED | 5mm red | 1 | Output indicator
RV1 | Potentiometer | 250KΩ | 1 | Select input sweep
(optional, I didn’t use them) SW1–SW3 | Push button | Tactile | 3 | D0, D1, S inputs
– | Breadboard | MB-102 | 1 | Prototyping
– | Power supply | 5V module | 1 | VCC rail

## 9 Conclusion

Building a 2-to-1 multiplexer entirely out of discrete transistors took more debugging than we originally expected, but that’s where we learned the most. Tracking down the ungrounded Q7 emitter taught us how important it is to trace voltages node by node instead of just guessing where the problem is.
The threshold experiment ended up being the highlight of the project. By sweeping the Select voltage with a potentiometer, we got to see the exact physical moment the transistor crosses from OFF to ON, which is the foundational physical behavior that makes all digital circuits possible.

## Project Repository

All project files, including the interactive circuit simulator, presentation slides, and build photos, are available on GitHub:

https://github.com/rowyfol/Elec101

Scan the QR code or visit the URL to access the full project repository.

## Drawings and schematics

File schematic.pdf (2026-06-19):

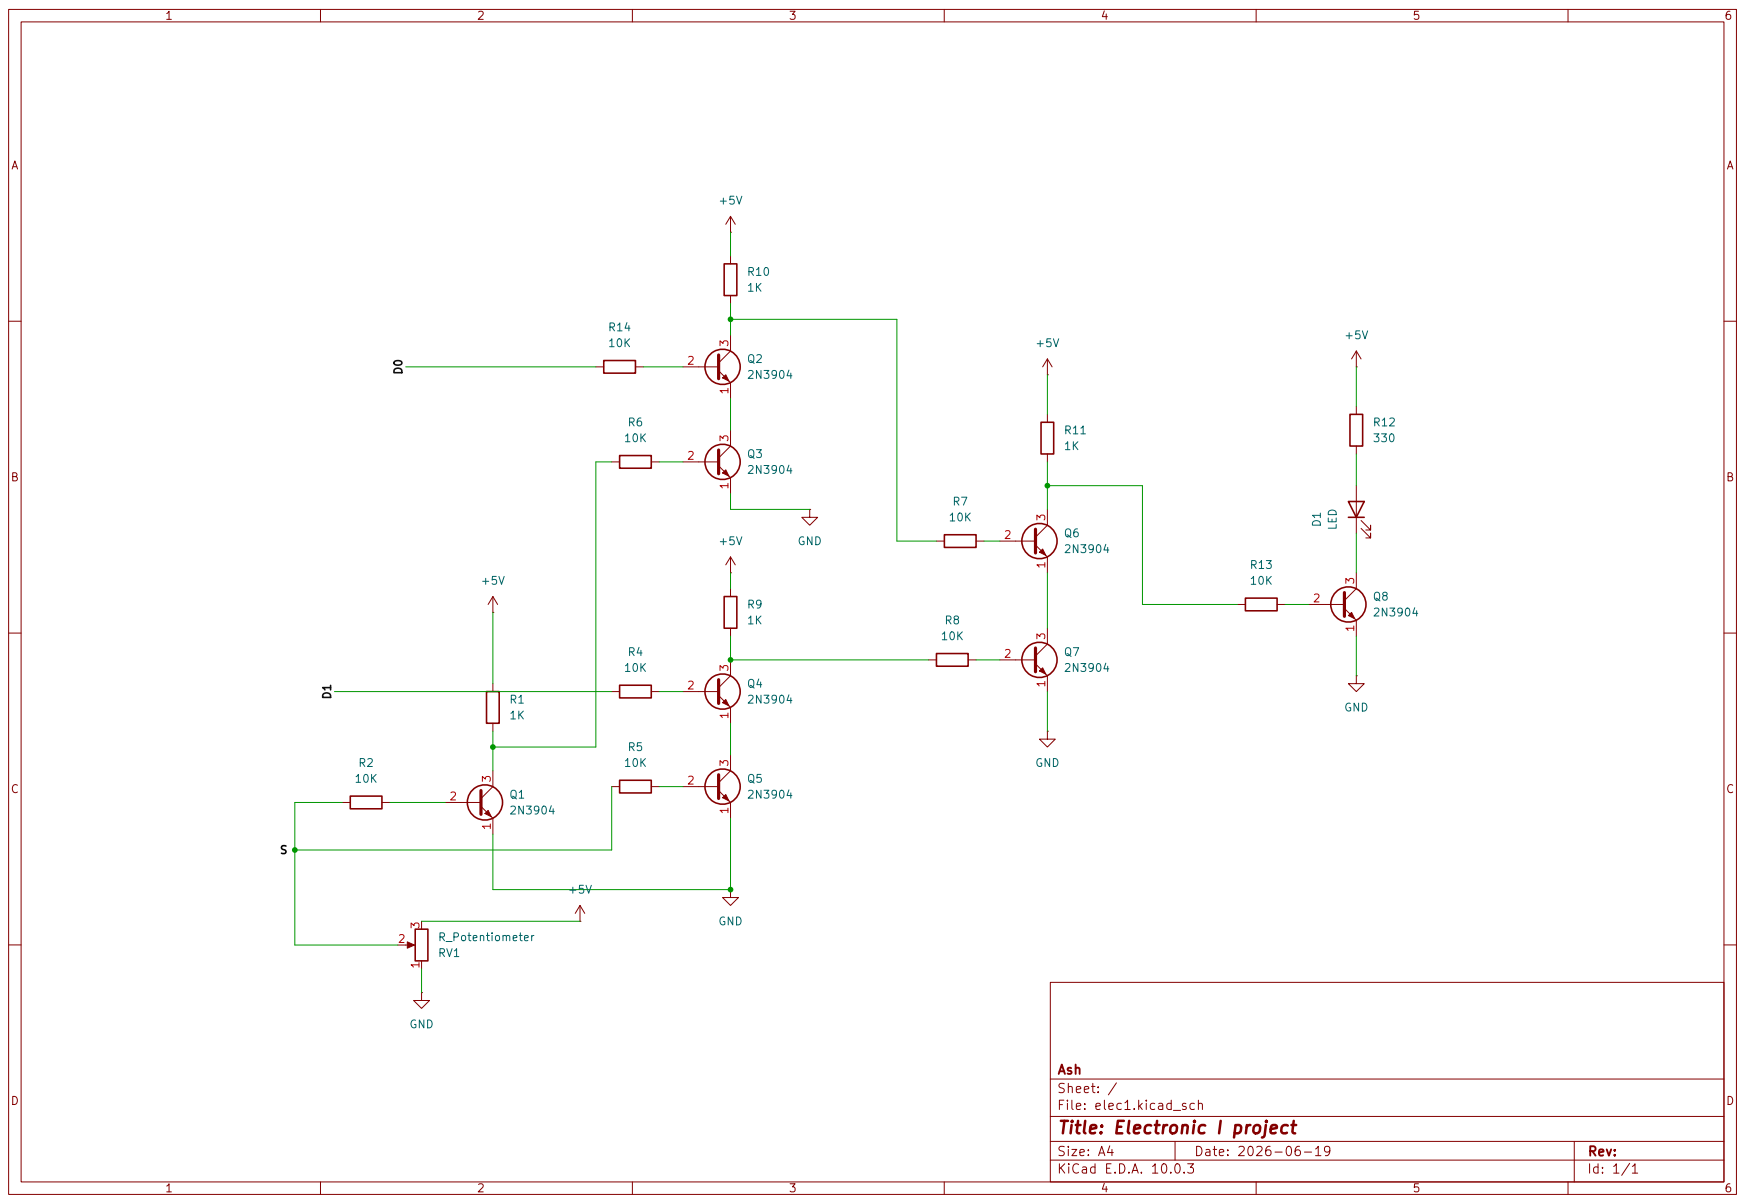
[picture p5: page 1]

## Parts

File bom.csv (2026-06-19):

Name | Quantity | Component
Q1, Q2, Q3, Q4, Q5, Q6, Q7, Q8 | 8 | NPN Transistor (BJT)
R1, R9, R10, R11 | 4 | 1 kΩ Resistor
R2, R4, R5, R6, R7, R8, R13 ,R14 | 8 | 10 kΩ Resistor
D1 | 1 | Green LED
R12 | 1 | 330 Ω Resistor
BAT1 | 1 | 9V Battery
U1 | 1 | 5V Regulator [LM7805]
RV1 | 1 | 250 kΩ Potentiometer
